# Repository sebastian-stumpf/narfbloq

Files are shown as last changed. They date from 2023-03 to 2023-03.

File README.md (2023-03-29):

# narfbloq

A wireless version of the narfpad.

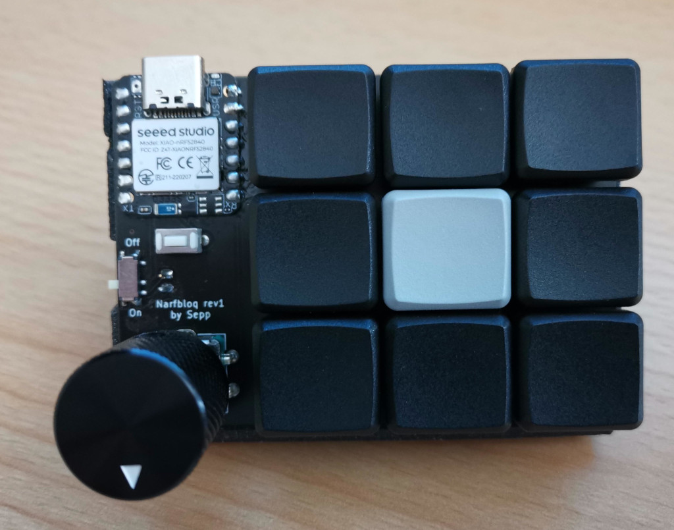
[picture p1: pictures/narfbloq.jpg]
narfbloq


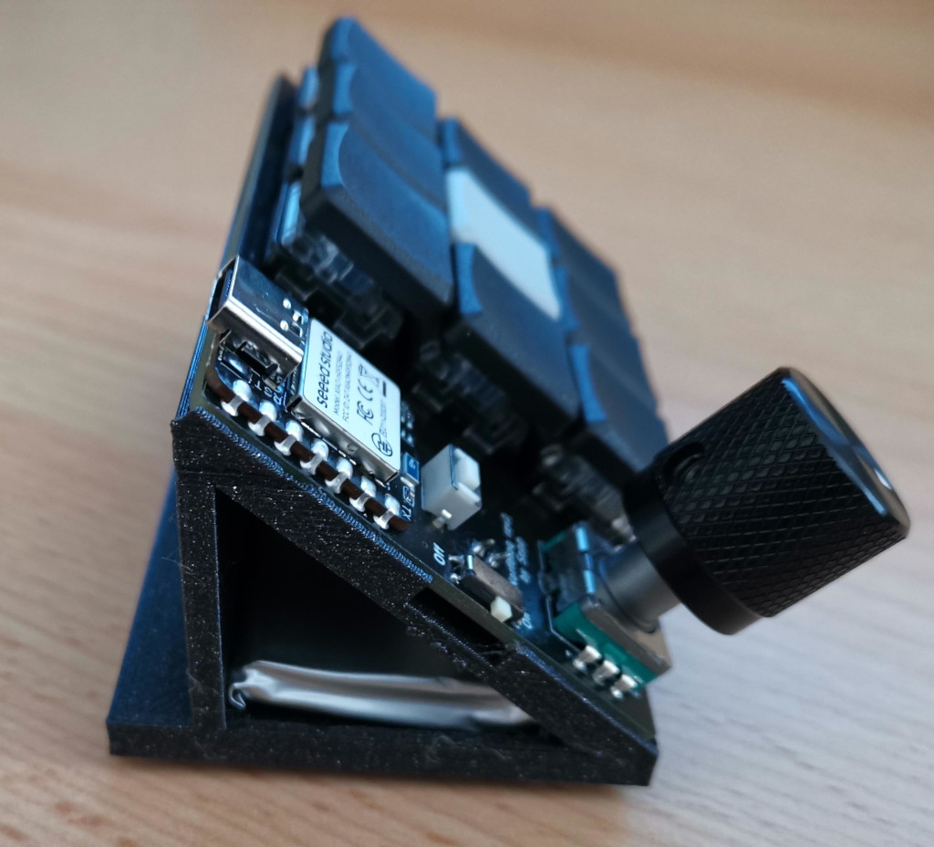
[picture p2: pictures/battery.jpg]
battery


## BOM

- narfpad PCB
- 1 Seeed Studio XIAO nRF52840
- 10 SOD123 diodes
- 9 Kailh Choc Hotswap Sockets
- 9 Choc Switches (and keycaps)
- 1 EC11 Encoder
- 1 Reset Button (optional but recommended since the one on the MCU is really tiny)
- 1 MSK-12C02 Switch
- 1 JST-PH 2mm connector
- 1 3.7V LiPo battery with JST-PH 2mm connector (I designed this for a 30x40x6.5 battery which fits the case nicely)
- 1 3D printed case (I scaled it to 102% and the PCB fits it quite nicely at that size)

## Firmware

Firmware available here:

https://github.com/sebastian-stumpf/zmk-config-narfbloq

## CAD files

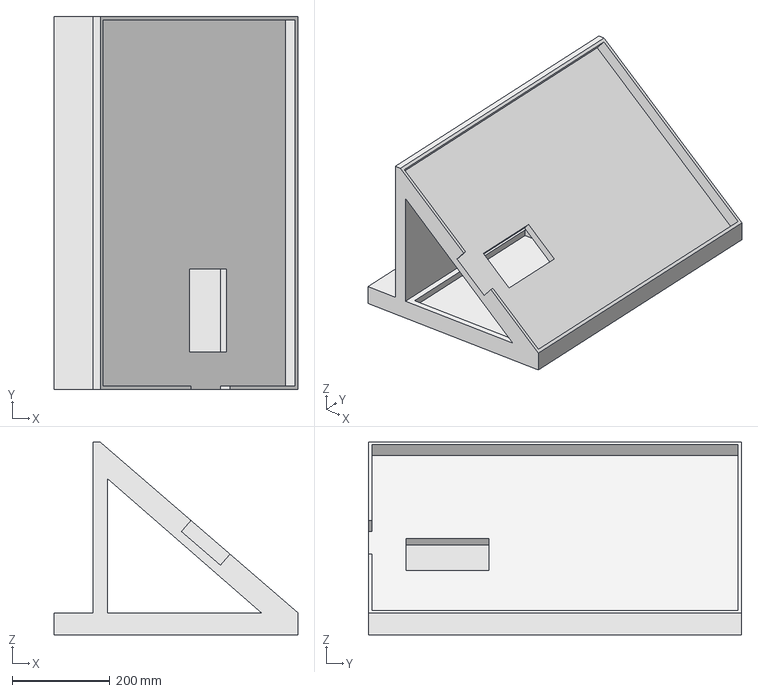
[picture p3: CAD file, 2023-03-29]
case.FCStd
500.0 x 765.0 x 394.6 mm

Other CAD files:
case.stl

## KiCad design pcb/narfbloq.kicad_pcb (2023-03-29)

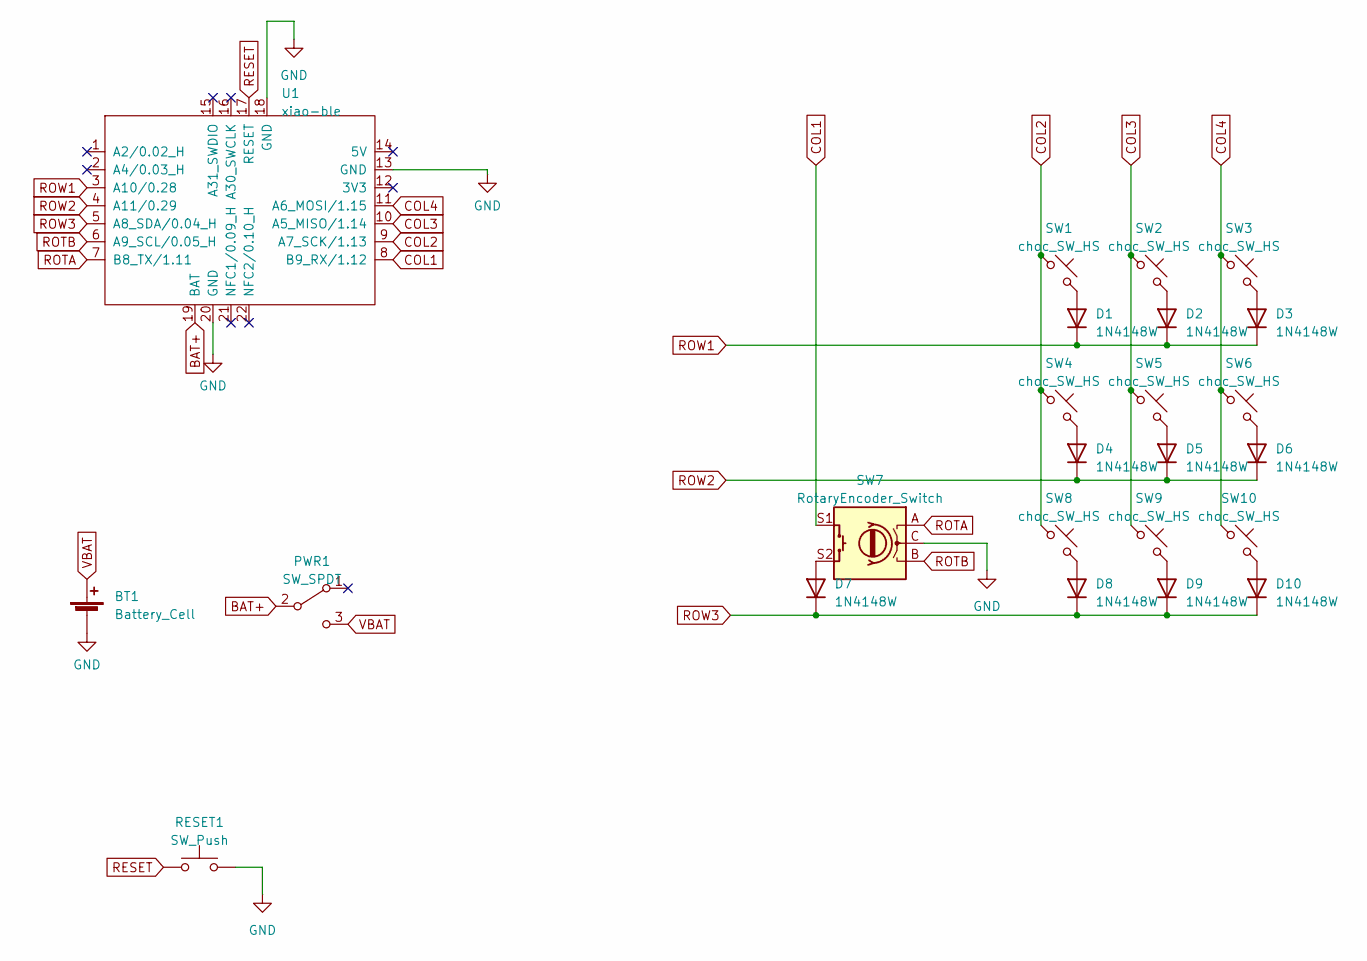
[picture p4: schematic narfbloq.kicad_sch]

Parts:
BT1: Battery_Cell; JST_PH_S2B-PH-K_1x02_P2.00mm_Horizontal
D1, D2, D3, D4, D5, D6, D7, D8, D9, D10: 1N4148W; D_SOD-123
PWR1: SW_SPDT; switch-MSK-12C02-smd
RESET1: SW_Push; ResetSW
SW1, SW2, SW3, SW4, SW5, SW6, SW8, SW9, SW10: choc_SW_HS; SW_choc_HS_1u
SW7: RotaryEncoder_Switch; RotaryEncoder_EC11
U1: xiao-ble; xiao-ble-tht

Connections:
BAT+: PWR1.2 (B), U1.19 (BAT)
COL1: SW7.S1, U1.8 (B9_RX/1.12)
COL2: SW1.1, SW4.1, SW8.1, U1.9 (A7_SCK/1.13)
COL3: SW2.1, SW5.1, SW9.1, U1.10 (A5_MISO/1.14)
COL4: SW3.1, SW6.1, SW10.1, U1.11 (A6_MOSI/1.15)
GND: BT1.2 (-), RESET1.2, SW7.C, U1.13 (GND), U1.18 (GND), U1.20 (GND)
unnamed: D1.2 (A), SW1.2
unnamed: D2.2 (A), SW2.2
unnamed: D3.2 (A), SW3.2
unnamed: D4.2 (A), SW4.2
unnamed: D5.2 (A), SW5.2
unnamed: D6.2 (A), SW6.2
unnamed: D7.2 (A), SW7.S2
unnamed: D8.2 (A), SW8.2
unnamed: D9.2 (A), SW9.2
unnamed: D10.2 (A), SW10.2
RESET: RESET1.1, U1.17 (RESET)
ROTA: SW7.A, U1.7 (B8_TX/1.11)
ROTB: SW7.B, U1.6 (A9_SCL/0.05_H)
ROW1: D1.1 (K), D2.1 (K), D3.1 (K), U1.3 (A10/0.28)
ROW2: D4.1 (K), D5.1 (K), D6.1 (K), U1.4 (A11/0.29)
ROW3: D7.1 (K), D8.1 (K), D9.1 (K), D10.1 (K), U1.5 (A8_SDA/0.04_H)
VBAT: BT1.1 (+), PWR1.3 (C)

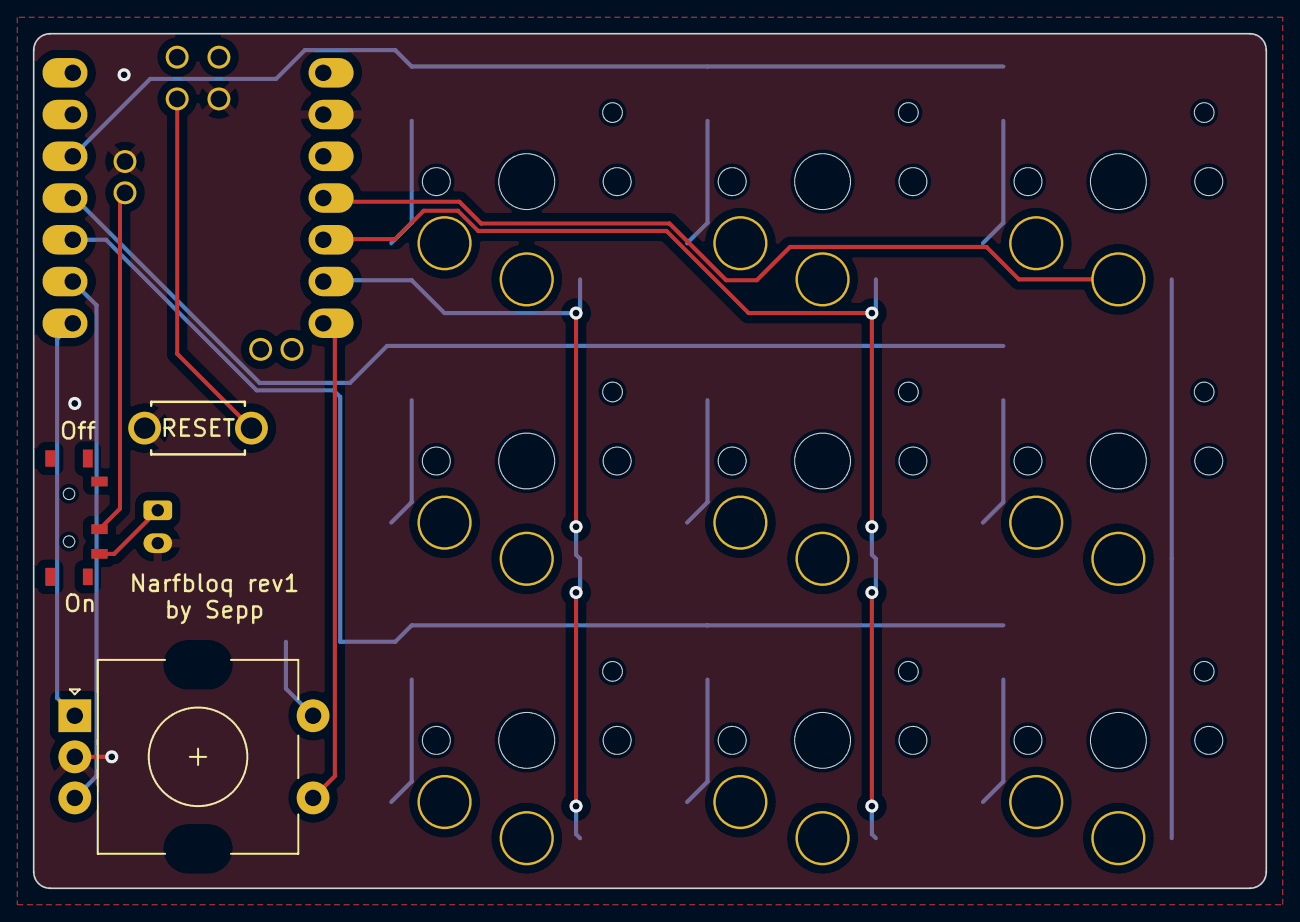
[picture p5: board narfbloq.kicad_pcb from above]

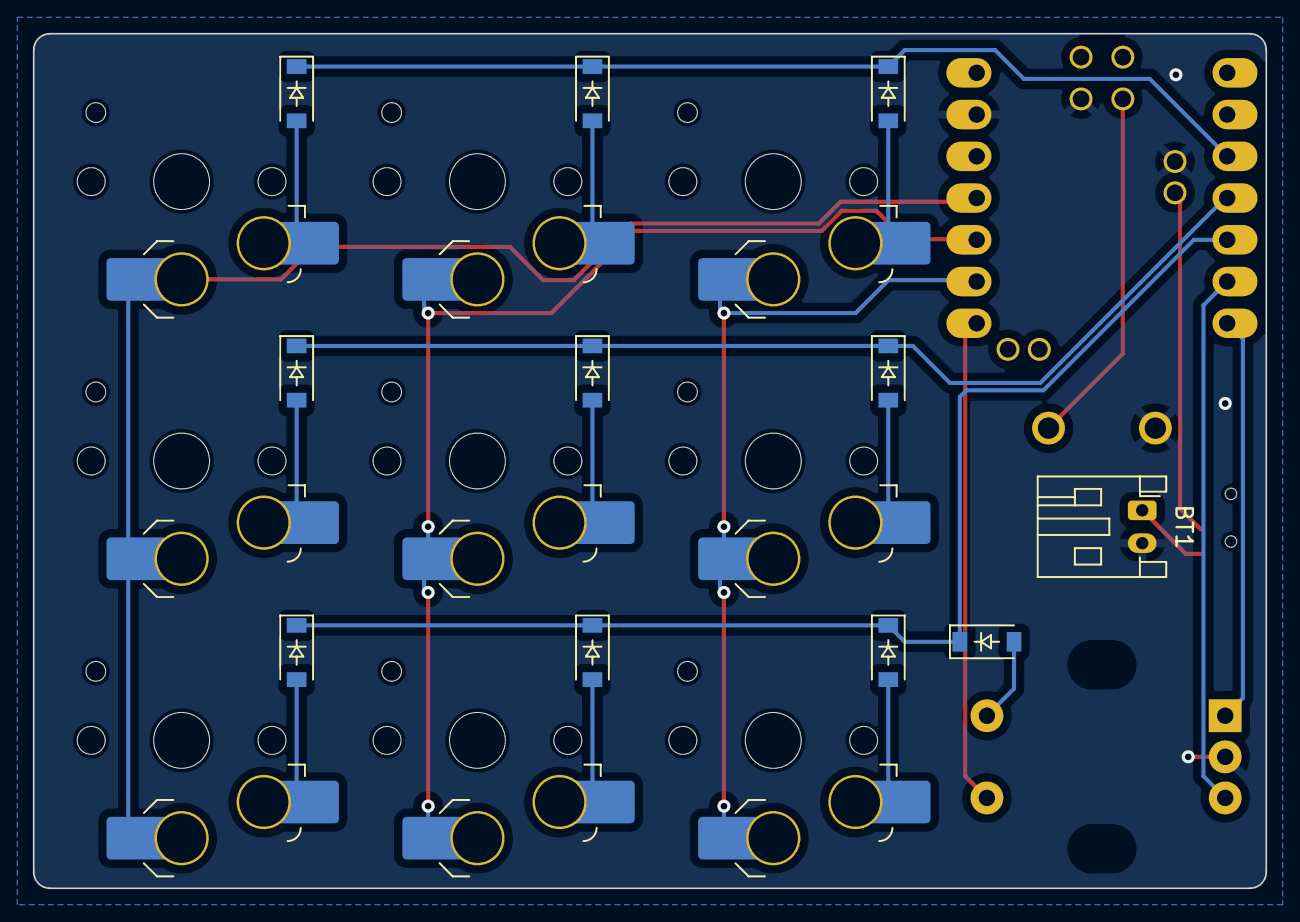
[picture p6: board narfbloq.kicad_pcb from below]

Board: 2 copper layers, 75.0 x 52.0 mm, 24 parts (11 on the bottom side), 23 nets.
